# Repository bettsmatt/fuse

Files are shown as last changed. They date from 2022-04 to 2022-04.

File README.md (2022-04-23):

# Fuse
A WIP split, 60%, wireless, low profile, choc spaced, magnetic keyboard. 

## Design Notes

* 3D printed case with embedded magnets to allow the two split boards to snap together into a single board. 
* Switches must be soldered as the footprint of hotswap sockets would space the switches too far apart.
* Through hole diode matrix as they look badass and SMD parts are a pain to solder. 
* Wireless (no TRRS), Nice!Nano with 3.7v batteries. Power Switch on PCB.
* PCBs are reversible for the left / right hand. Nice!Nano pins mirrored in ZMK firmware.

## PCB



fuse-brd

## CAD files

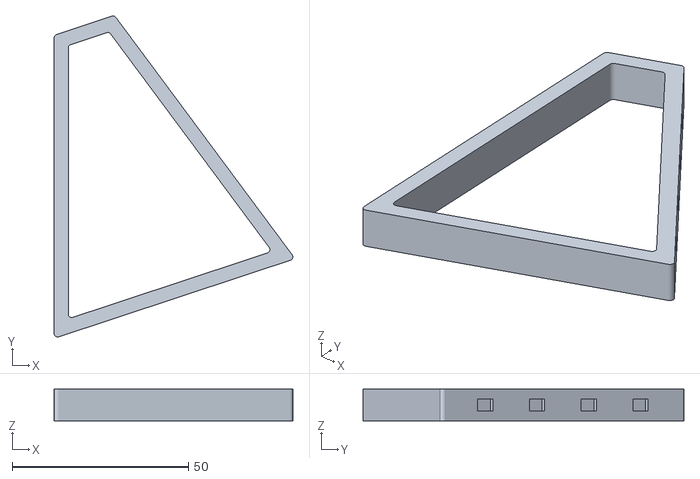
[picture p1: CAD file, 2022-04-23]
pcb/Divider.stl
67.7 x 91.1 x 9.00

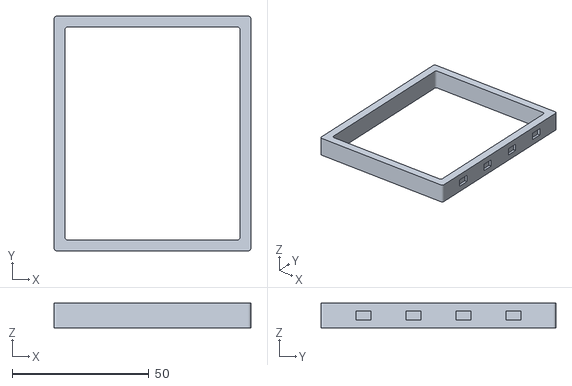
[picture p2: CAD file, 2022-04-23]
pcb/Divider-72-72.stl
72.0 x 86.0 x 9.00

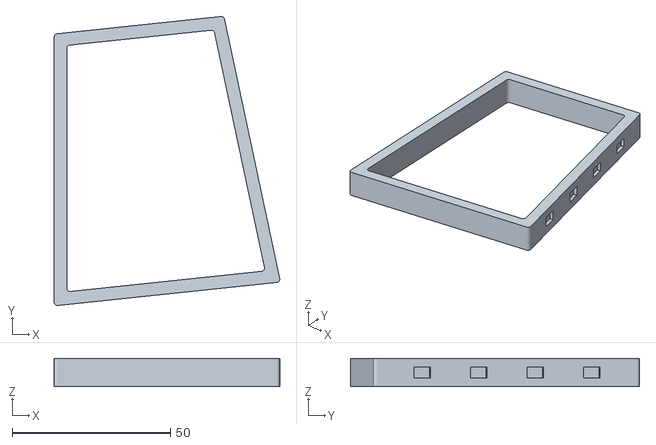
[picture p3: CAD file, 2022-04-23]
pcb/Divider-54-72.stl
71.4 x 91.4 x 9.00

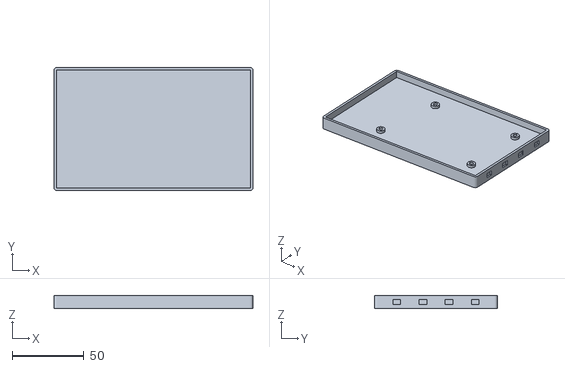
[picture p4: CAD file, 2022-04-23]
pcb/Case.stl
139.0 x 86.0 x 9.00

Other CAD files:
pcb/case.stl

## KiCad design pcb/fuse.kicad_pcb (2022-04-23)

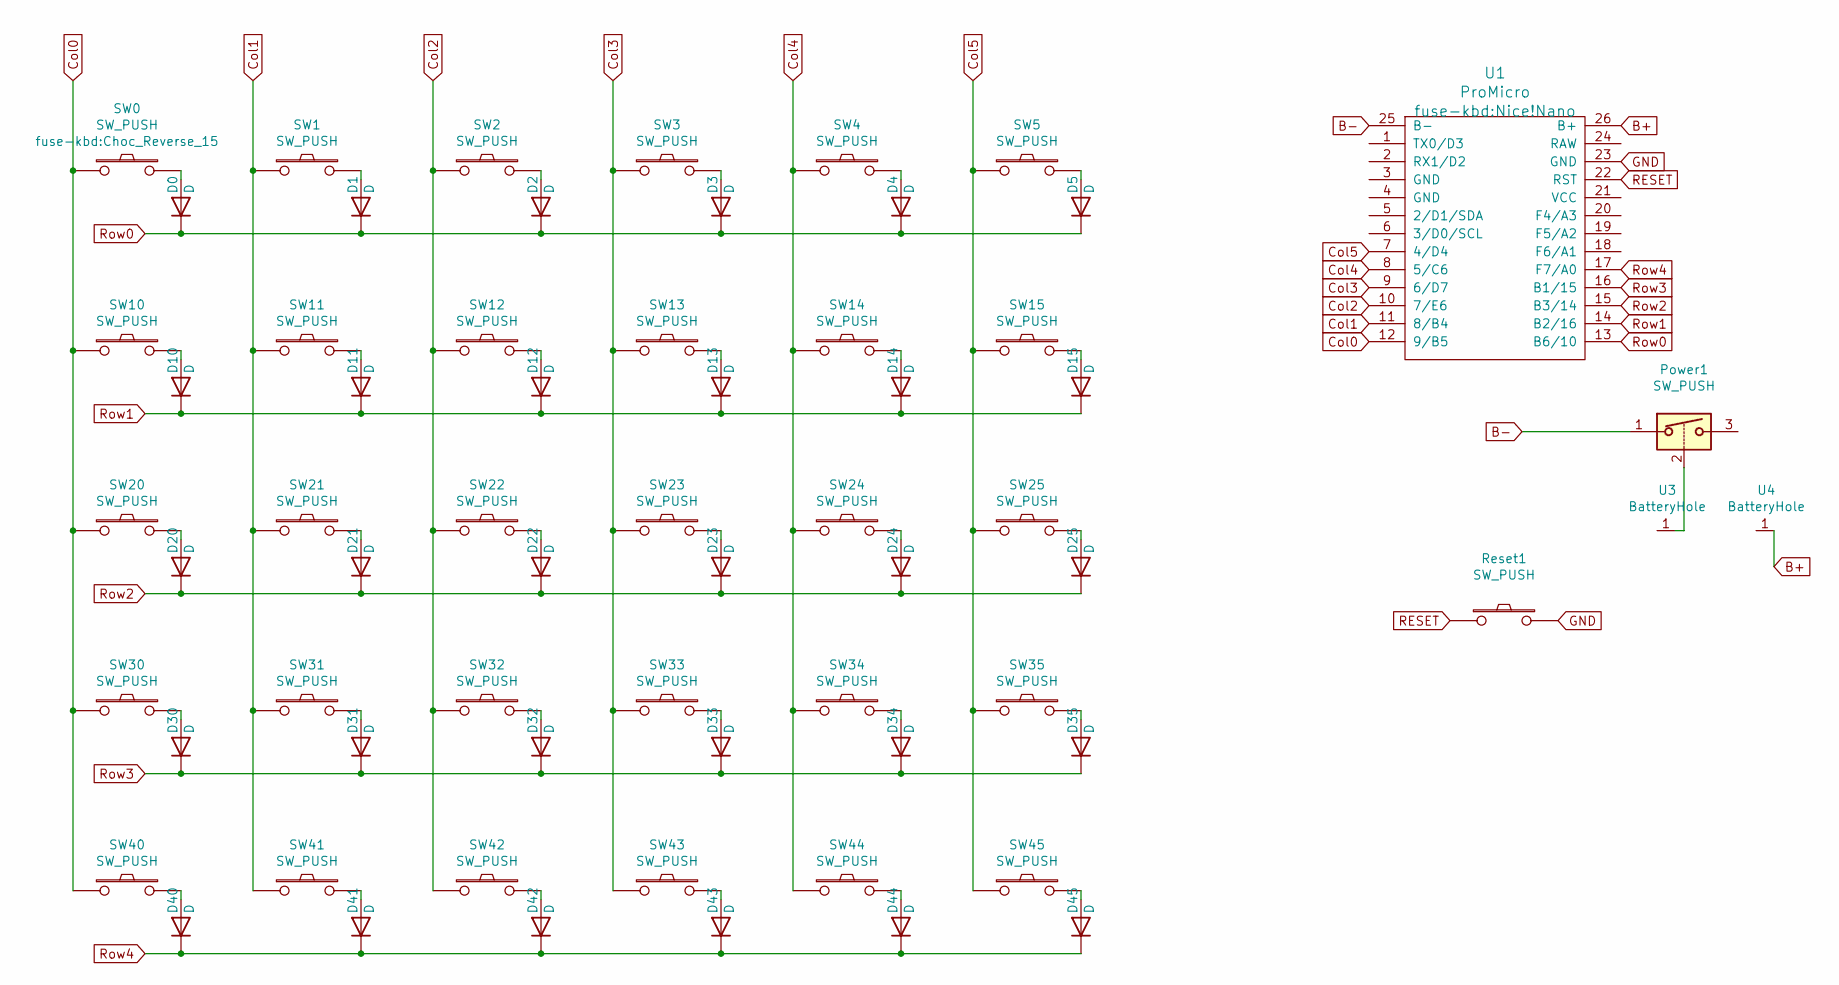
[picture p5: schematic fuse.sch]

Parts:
D0, D1, D2, D3, D4, D5, D10, D11, D12, D13, D14, D15, D20, D21, D22, D23, D24, D25, D30, D31, D32, D33, D34, D35, D40, D41, D42, D43, D44, D45: D; R
Power1: SW_PUSH; EG1218
Reset1: SW_PUSH; Reset
SW0, SW10, SW20, SW30, SW45: SW_PUSH; Choc_Reverse_15
SW1, SW2, SW3, SW4, SW5, SW11, SW12, SW13, SW14, SW15, SW21, SW22, SW23, SW24, SW25, SW31, SW32, SW33, SW34, SW35, SW40, SW41, SW42, SW43, SW44: SW_PUSH; Choc_Reverse
U1: ProMicro; Nice!Nano
U3, U4: BatteryHole; BatteryPins

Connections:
B+: U1.26 (B+), U4.1
B-: Power1.1, U1.25 (B-)
Col0: SW0.1, SW10.1, SW20.1, SW30.1, SW40.1, U1.12 (9/B5)
Col1: SW1.1, SW11.1, SW21.1, SW31.1, SW41.1, U1.11 (8/B4)
Col2: SW2.1, SW12.1, SW22.1, SW32.1, SW42.1, U1.10 (7/E6)
Col3: SW3.1, SW13.1, SW23.1, SW33.1, SW43.1, U1.9 (6/D7)
Col4: SW4.1, SW14.1, SW24.1, SW34.1, SW44.1, U1.8 (5/C6)
Col5: SW5.1, SW15.1, SW25.1, SW35.1, SW45.1, U1.7 (4/D4)
GND: Reset1.2, U1.23 (GND)
unnamed: D0.2 (A), SW0.2
unnamed: D1.2 (A), SW1.2
unnamed: D2.2 (A), SW2.2
unnamed: D3.2 (A), SW3.2
unnamed: D4.2 (A), SW4.2
unnamed: D5.2 (A), SW5.2
unnamed: D10.2 (A), SW10.2
unnamed: D11.2 (A), SW11.2
unnamed: D12.2 (A), SW12.2
unnamed: D13.2 (A), SW13.2
unnamed: D14.2 (A), SW14.2
unnamed: D15.2 (A), SW15.2
unnamed: D20.2 (A), SW20.2
unnamed: D21.2 (A), SW21.2
unnamed: D22.2 (A), SW22.2
unnamed: D23.2 (A), SW23.2
unnamed: D24.2 (A), SW24.2
unnamed: D25.2 (A), SW25.2
unnamed: D30.2 (A), SW30.2
unnamed: D31.2 (A), SW31.2
unnamed: D32.2 (A), SW32.2
unnamed: D33.2 (A), SW33.2
unnamed: D34.2 (A), SW34.2
unnamed: D35.2 (A), SW35.2
unnamed: D40.2 (A), SW40.2
unnamed: D41.2 (A), SW41.2
unnamed: D42.2 (A), SW42.2
unnamed: D43.2 (A), SW43.2
unnamed: D44.2 (A), SW44.2
unnamed: D45.2 (A), SW45.2
unnamed: Power1.2, U3.1
RESET: Reset1.1, U1.22 (RST)
Row0: D0.1 (K), D1.1 (K), D2.1 (K), D3.1 (K), D4.1 (K), D5.1 (K), U1.13 (B6/10)
Row1: D10.1 (K), D11.1 (K), D12.1 (K), D13.1 (K), D14.1 (K), D15.1 (K), U1.14 (B2/16)
Row2: D20.1 (K), D21.1 (K), D22.1 (K), D23.1 (K), D24.1 (K), D25.1 (K), U1.15 (B3/14)
Row3: D30.1 (K), D31.1 (K), D32.1 (K), D33.1 (K), D34.1 (K), D35.1 (K), U1.16 (B1/15)
Row4: D40.1 (K), D41.1 (K), D42.1 (K), D43.1 (K), D44.1 (K), D45.1 (K), U1.17 (F7/A0)

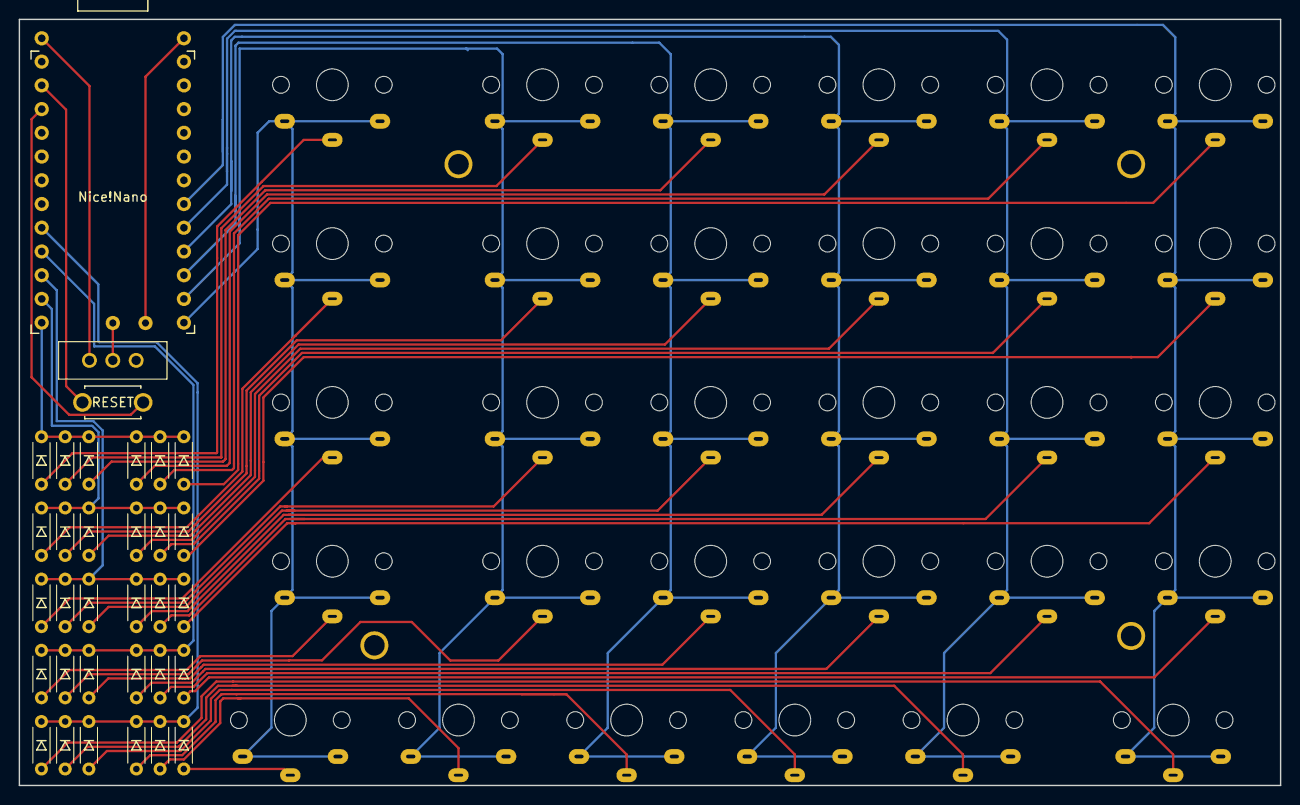
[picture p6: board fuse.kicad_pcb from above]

Board: 2 copper layers, 135.0 x 82.0 mm, 65 parts (0 on the bottom side), 46 nets.

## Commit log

2022-03-06 Added PCB files.
    [fuse.kicad_pcb, fuse.sch]
2022-03-06 Remove hotswap to cut down PCB size.
    [fuse.kicad_pcb, fuse.sch]
2022-03-08 fix reset pin and footprints
    [fuse.kicad_pcb, fuse.sch]
2022-04-23 Changes for v1 PCB and case
    [Case.stl, Divider-54-72.stl, Divider-72-72.stl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]
